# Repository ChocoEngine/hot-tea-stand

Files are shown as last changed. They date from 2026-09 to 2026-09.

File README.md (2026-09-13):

# Hot tea stand

## План оставшихся работ

1. Проверить работу датчиков и схемы: прозвонить соединения и допаять.
2. Поправить модель корпуса: исправить расположение отверстия для USB.
3. Подправить уже напечатанный корпус.
4. Отладить соединение с Zigbee-хабом SprutHub.
5. Дописать код для температурного графика.

Подставка под чашку с ESP32-C6 и NTC 3950. Структура обновлена 13 сентября 2026 года; геометрия не изменялась.

## Фотографии прототипа

Напечатанный корпус с декоративной накладкой:

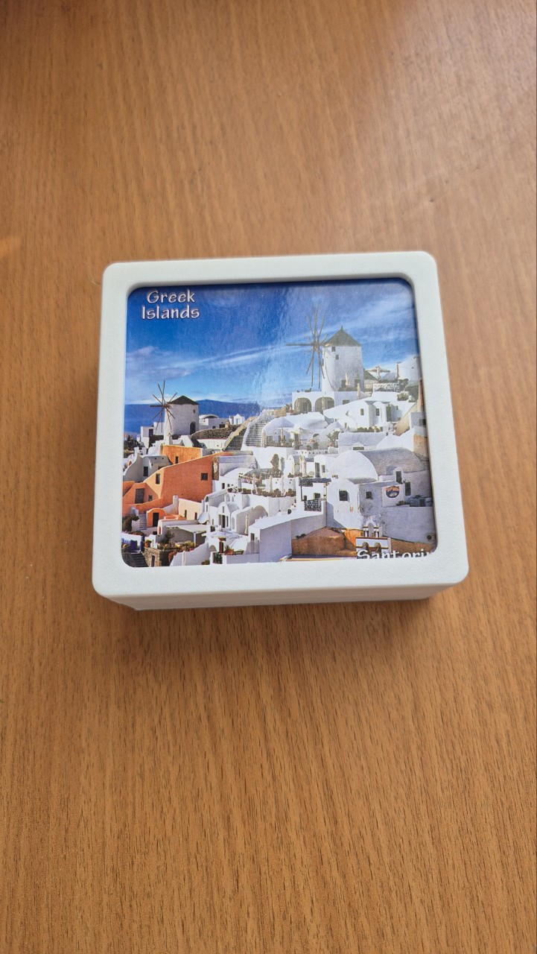
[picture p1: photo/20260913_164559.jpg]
Корпус подставки с декоративной накладкой


Внутреннее размещение ESP32-C6 на проектной плате и снятая нижняя крышка:

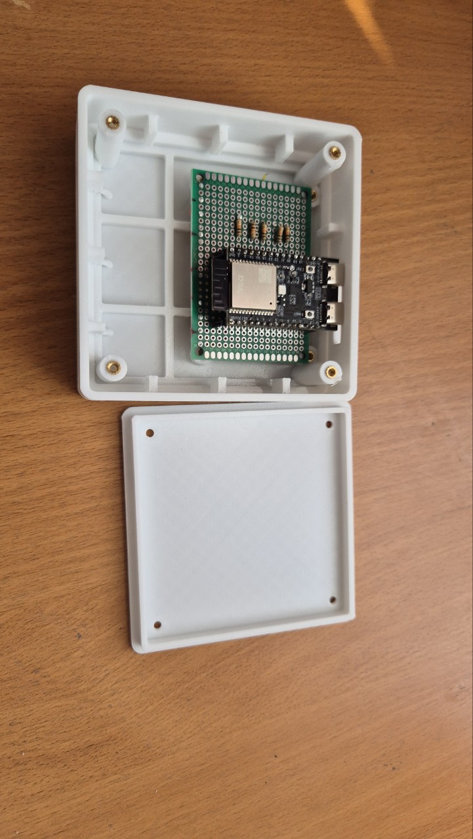
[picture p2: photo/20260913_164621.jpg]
ESP32-C6 на проектной плате внутри корпуса и нижняя крышка


## Структура

| Папка | Содержимое |
| --- | --- |
| [models/current](models/current/) | Последние модели 102 мм: исходная сборка `esp32_inverted_box_102mm_snap_lid.3dm` и результат вычитаний `esp32_inverted_box_102mm_final.3dm` |
| [models/archive](models/archive/) | Предыдущие версии 100 мм |
| [models/sketches](models/sketches/) | Рабочие эскизы `maket.3dm` |
| [models/templates](models/templates/) | Шаблон подрезки накладки 95 × 95 мм, R5 |
| [models/examples](models/examples/) | Пример прижима NTC к шайбе |
| [exports](exports/) | Сохранённые STL и 3MF; резервный STL — в `exports/archive/` |
| [scripts](scripts/) | Генерация моделей, вычитания и проверки |
| [code](code/) | Код для ESP32 и инструкция запуска |
| [docs](docs/) | Исторические заметки по корпусу и прижиму |
| [schematics](schematics/) | Схемы монтажа и макетной платы |
| [references](references/) | Фотографии и скриншоты |
| [photo](photo/) | Фотографии напечатанного прототипа и внутреннего монтажа |
| [archive/generated-cache](archive/generated-cache/) | Старый Python-кеш; для запуска не нужен |

## Актуальность файлов

`current` означает последние сохранённые файлы, а не новую проверку пригодности к печати. Соответствие `temp_box.stl` и `temp_box.3mf` последней модели не подтверждено. Ручная подрезка USB на напечатанном корпусе не означает, что CAD-файл исправлен.

Фактическая накладка оказалась размером 98 мм; отдельно сохранён шаблон подрезки до 95 мм, R5.

## Запуск скриптов

Из корня проекта:

```sh
python3 scripts/create_esp32_inverted_box_3dm.py
python3 scripts/finalize_esp32_box.py
python3 scripts/validate_esp32_box_3dm.py
python3 scripts/validate_esp32_box_final.py
```

Первые две команды перезаписывают исходную и финальную модели в `models/current/`. Перед запуском сохраняйте отдельную копию ручных изменений в Rhino: генераторы могут их не воспроизводить.

Отдельные генераторы:

```sh
python3 scripts/create_overlay_cut_template.py
python3 scripts/create_ntc_clamp_3dm.py
```

Результаты записываются в `models/templates/` и `models/examples/`. Пути вычисляются относительно скриптов и не зависят от текущей папки терминала.

Зависимости: `rhino3dm`, для операций с сетками также `numpy`, `trimesh`, `manifold3d`. Сохранены прежние дополнительные пути библиотек `/tmp/codex_rhino3dm` и `/tmp/codex_meshlibs`: это временные окружения, наличие библиотек там не гарантировано. При уборке проверен синтаксис скриптов; генерация и геометрические проверки не запускались.

## Документация и схемы

Скетч проверки пяти NTC на GPIO2–6: [code/ntc_test/ntc_test.ino](code/ntc_test/ntc_test.ino).
Подключение и запуск описаны в [code/README.md](code/README.md).

- [Заметки по корпусу](docs/README_esp32_box_ru.md) и [прижиму](docs/README_ntc_clamp_ru.md) сохранены как исторические документы: пути и размеры в них могут относиться к предыдущим итерациям.
- `schematics/esp32-perfboard-placement.html` — ранняя схема проектной платы.
- `schematics/esp32-final-perfboard-layout.html` — более поздний вариант размещения.
- `schematics/two-ntc-breadboard.html` — макет с двумя датчиками.

В схемах есть разные варианты делителя: резистор к 3V3 / NTC к GND и наоборот. Формула температуры должна соответствовать выбранному подключению. HTML сохранены как исходные фрагменты визуализаций.

Фотографии в `references/` собраны из обсуждения; их оригиналы по прежним адресам оставлены для сохранения ссылок в чате.

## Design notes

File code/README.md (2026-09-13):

# Код проверки NTC

`ntc_test/ntc_test.ino` — минимальный скетч Arduino для ESP32-C6:
пять NTC на GPIO2, GPIO3, GPIO4, GPIO5 и GPIO6, усреднение 16 измерений,
вывод напряжений в милливольтах примерно раз в секунду.
Сторонние библиотеки датчиков не нужны; используется Arduino core для ESP32.

Каждый датчик подключён отдельным делителем:

```text
3.3V ── NTC ──┬── постоянный резистор ── GND
              └── GPIO (2–6)
```

При нагревании NTC напряжение увеличивается.

Открой `ntc_test/ntc_test.ino` в Arduino IDE, выбери свою плату ESP32-C6
и порт, загрузи скетч. Скорость Serial Monitor — 115200 бод.

Температура пока не рассчитывается: нужны сопротивления постоянных
резисторов, номиналы NTC при 25 °C и коэффициенты B.

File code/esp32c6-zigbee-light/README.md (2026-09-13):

# ESP32-C6 N8: диагностическая Zigbee-лампа для SprutHub

Проект для ESP-IDF **5.3.2**, ESP Zigbee SDK **1.6.x** и ESP32-C6 с Flash 8 МБ.
Используется поддерживаемая LTS-ветка SDK 1.x для сравнения с Arduino; SDK 2.x имеет другой API и сюда не подставляется.
Зависимости загружает IDF Component Manager. После первой успешной сборки сохраните dependencies.lock для воспроизводимости.

## Поведение

- Zigbee End Device, endpoint 10, HA On/Off Light (0x0100).
- Производитель Espressif, модель ZBLightBulb; строки сохранены как в Arduino-тесте.
- Поиск подключения на канале 25, повтор после неудачи.
- В журнале: события Zigbee, успешное подключение с PAN ID/адресом/каналом, команды On/Off.
- Лампа виртуальная: GPIO нагрузки и встроенный RGB не управляются.
- BOOT (GPIO9), удерживаемая 3 секунды во время работы, сбрасывает Zigbee-привязку и перезапускает плату.
- Привязка сохраняется при обычном перезапуске.

## Открытие в VS Code

1. Установите официальное расширение **ESP-IDF** от Espressif Systems.
2. Установите/выберите **ESP-IDF 5.3.2** средствами расширения.
3. Откройте эту папку (с корневым CMakeLists.txt).
4. Запустите команду **ESP-IDF: Open ESP-IDF Terminal**.
5. Подключите левый USB-C **CH343**, выберите его последовательный порт.

## Сборка и первая прошивка

В терминале ESP-IDF, из папки проекта:

```sh
idf.py set-target esp32c6
idf.py build
idf.py -p /dev/cu.usbmodem5B3E0587871 erase-flash
idf.py -p /dev/cu.usbmodem5B3E0587871 flash monitor
```

Порт приведён из прежнего лога, он может измениться. Узнать доступные порты на macOS:

```sh
ls /dev/cu.*
```

**erase-flash нужен только при первом переходе с Arduino на эту разметку. Он удаляет всю прошивку и сохранённые данные платы, включая Zigbee-привязку.** Последующие обновления: `idf.py -p ПОРТ flash monitor` без стирания.
Закройте Serial Monitor Arduino IDE перед прошивкой. Выход из IDF Monitor: Ctrl+].

Если автоматический вход в загрузчик не работает: зажмите BOOT, нажмите и отпустите RST, отпустите BOOT и повторите flash. После прошивки нажмите RST при необходимости.

## Сопряжение

1. В SprutHub включите поиск на ZigBee_1.
2. На работающей плате удерживайте BOOT 3 секунды (не при подаче питания).
3. Дождитесь `Joined network successfully`.
4. Если вновь `Network steering was not successful`, сохраните полный вывод от `TEST-IDF-1` за 60 секунд и журнал хаба за то же время.

ESP_FAIL остаётся общим кодом: проект выводит доступные события SDK, но не является радиосниффером и не гарантирует раскрытие причины отказа. Для представления подключившейся лампы в интерфейсе SprutHub может понадобиться шаблон.

Канал меняется в main/esp_zb_light.h, ESP_ZB_PRIMARY_CHANNEL_MASK. Разметка включает zb_storage и zb_fct. Занята только часть 8 МБ; OTA в этом тесте нет.

## Проверка и источники

Структура проекта, API по заголовкам SDK и отсутствие пересечений разделов проверены. **Сборка и запуск на плате не проверены: ESP-IDF в среде подготовки не установлен.**

Основано на примере Espressif HA_on_off_light (CC0-1.0):
https://github.com/espressif/esp-zigbee-sdk/tree/release/v1.0/examples/esp_zigbee_HA_sample/HA_on_off_light

Совместимость ESP-IDF 5.3.2 рекомендована в README выбранной ветки:
https://github.com/espressif/esp-zigbee-sdk/tree/release/v1.0

Библиотеки esp-zigbee-lib и esp-zboss-lib имеют собственные лицензии; см. загружаемые компоненты.

## Если конфигуратор выбрал ESP-IDF 6.1 или target esp32

Этот проект использует API Zigbee SDK 1.x и требует ESP-IDF 5.3.x (от 5.3.2). Удалять ограничение в idf_component.yml нельзя: это не перенос на SDK 2.x.

В палитре VS Code (Cmd+Shift+P):
1. ESP-IDF: Open ESP-IDF Installation Manager — установите ESP-IDF 5.3.2 для esp32c6 рядом с 6.1.
2. ESP-IDF: Select Current ESP-IDF Version — выберите установленную 5.3.2.
3. ESP-IDF: Set Espressif Device Target — esp32c6.
4. Откройте новый ESP-IDF Terminal и выполните `idf.py --version`, затем `idf.py set-target esp32c6` и `idf.py build`.

Если старый каталог build мешает set-target, переименуйте его в build-old, сохранив для диагностики. Корневой CMakeLists.txt явно задаёт esp32c6; PROJECT_VER задан независимо от наличия коммитов Git.

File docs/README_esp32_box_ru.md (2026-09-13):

# Корпус ESP32-C6 102 × 102 мм с верхней рамкой

Актуальная модель — `esp32_inverted_box_102mm_snap_lid.3dm`. Файл создаётся
скриптом `create_esp32_inverted_box_3dm.py`. Предыдущие варианты не
перезаписываются.

## Основные размеры

- корпус: 102 × 102 × 32 мм, наружные углы R5;
- толщина основных стенок и крыши: 3 мм;
- верхнее сужение: 12 мм общей высоты;
- у основания сужения — горизонтальная опорная полка шириной 1 мм;
- после неё — скос 2 × 2 мм под 45° от 100 × 100 до 96 × 96 мм;
- следующие 10 мм — прямой участок 96 × 96 мм;
- верхняя крышка-рамка: снаружи 102 × 102 мм, R5;
- на нижнем крае крышки предусмотрен внутренний ответный скос 45° высотой 2 мм;
- накладка: 95 × 95 × 4 мм;
- карман крышки под накладку: 95,4 × 95,4 × 4,1 мм;
- квадратное окно крышки: 87 × 87 мм, углы R5;
- нахлёст рамки на накладку: 4 мм с каждой стороны;
- толщина верхней рамки: 3 мм;
- внешний верхний край крышки имеет фаску 1 × 1 мм под 45°.

Наружный контур крышки по всей высоте остаётся 102 × 102 мм. Внутренняя
полость у нижнего края начинается размером 100,4 × 100,4 мм и за 2 мм по
скосу 45° сужается до 96,4 × 96,4 мм. После этого она охватывает прямой участок
корпуса 96 × 96 мм с зазором 0,2 мм на сторону.

Крышка опускается до Z = 20 мм и нижней гранью упирается в горизонтальную
полку корпуса. Её внутренний скос повторяет наружный скос корпуса с зазором
0,2 мм на сторону. Стенка крышки у открытого края имеет печатаемую толщину
0,8 мм, а внешний контур 102 × 102 мм совпадает с основным корпусом.

## Защёлки

На каждой стороне прямого сужения находится одна впадина:

- длина 18 мм;
- высота 5 мм;
- глубина 0,8 мм;
- скосы высотой 1 мм сверху и снизу;
- положение по высоте корпуса: Z = 24…29 мм.

На крышке предусмотрены ответные выступы длиной 16 мм, высотой 5 мм и вылетом
0,65 мм. У каждого выступа также есть верхний и нижний скос по 1 мм. Размеры
рассчитаны как стартовые для PETG; перед полной печатью всё ещё желательно
проверить одну отдельную защёлку.

## Электроника и NTC

Внутренняя поверхность крыши находится на Z = 29 мм. Проектная плата
70 × 50 × 1 мм расположена в диапазонах X = 16…86, Y = 7…57 и
Z = 22…23 мм. Между ней и крышей оставлено 6 мм.

Центры монтажных отверстий Ø3 мм находятся в 2,5 мм от краёв платы:

- (18,5; 9,5);
- (83,5; 9,5);
- (18,5; 54,5);
- (83,5; 54,5).

Четыре верхние стойки переделаны под вплавляемые втулки M3 D4,5 × L4:

- наружный диаметр стойки: 9 мм;
- посадочное отверстие: Ø4,1 мм;
- глубина отверстия: 4,5 мм;
- входной скос: Ø5,1 → Ø4,1 мм, глубина 0,5 мм;
- остаток пластика между дном отверстия и крышей: 1,5 мм;
- втулки устанавливаются снизу до монтажа проектной платы.

Ниже платы показаны съёмные гребёнки высотой 8 мм и ESP32-C6 с расчётным
вертикальным габаритом 6 мм. Электронный объём занимает Z = 8…22 мм. ESP
повёрнута USB к передней стенке и смещена влево: X = 50…78 мм. Длина от
выступающей плоскости USB до края антенны принята равной 53 мм.

Для наглядности гребёнки показаны двумя отдельными рядами в предполагаемых
координатах X = 51,56 и 76,96 мм, Y = 12,08…47,64 мм. Это предварительная
привязка к сетке 2,54 мм, которую нужно сверить с реальными отверстиями платы.

Пять отверстий Ø4 мм под NTC 3950 расположены на линии Y = 51 мм. Их X:
27, 39, 51, 63 и 75 мм, шаг 12 мм. Общая длина линии датчиков — 48 мм.
Такое положение выводит крайние отверстия из объёма задних стоек проектной
платы.

Универсальное переднее окно двух USB-C имеет размер 30 × 6 мм:

- X = 49…79 мм;
- Z = 8,5…14,5 мм;
- отдельные рёбра и рамка усиления вокруг окна отсутствуют;
- над окном остаётся 5,5 мм цельной трёхмиллиметровой стенки до скоса.

Высота металлического корпуса USB принята равной 5 мм; окно оставляет суммарно
1 мм вертикального монтажного запаса.

Под всей проектной платой оставлен свободный объём с запасом 2 мм по контуру:
X = 14…88, Y = 5…59 и Z = 23…29 мм. Поэтому для выводов NTC и проводов
доступна полная высота 6 мм. В эту область входят только четыре крепёжные
стойки самой платы.

Рёбра крыши сохранены за задним краем платы, около боковых стенок и короткими
участками около передних углов. Передние стеновые рёбра расположены на X = 35
и X = 92 мм и не попадают под головки крепёжных винтов. На справочном слое
показаны свободные цилиндры Ø6 × 2,5 мм под головки винтов.

Локальные усиления вокруг USB удалены: при окне высотой 6 мм они не требуются
и мешали доступу к ближайшей стойке проектной платы.

Справочная накладка вынесена отдельно. На ней показаны пять тел для слепых
карманов 3 × 3 мм глубиной 3,1 мм.

## Нижнее винтовое дно

Дно имеет пластину 102 × 102 × 3 мм, R5, и внутренний центрирующий бортик
высотой 6 мм. Оно крепится четырьмя потайными машинными винтами M3 × 8 мм
DIN 7991 / ISO 10642.

Угловые стойки рассчитаны под вплавляемые гайки M3 D4,5 × L4:

- центры: (11; 11), (91; 11), (11; 91), (91; 91);
- наружный диаметр стойки: 9 мм;
- посадочное отверстие: Ø4,1 мм;
- глубина: 5 мм;
- входной скос: Ø5,1 → Ø4,1 мм, глубина 0,5 мм.

В дне предусмотрены отверстия Ø3,5 мм и потаи Ø7 → Ø3,5 мм глубиной 1,75 мм.

## Размещение деталей и слои

Корпус и обе крышки показаны в собранном положении и имеют общий диапазон
X = 0…102 мм:

- нижнее винтовое дно: пластина Z = −3…0 мм, вставной бортик до Z = 6 мм;
- корпус: Z = 0…32 мм;
- верхняя крышка-рамка: Z = 20…39,1 мм;
- справочная накладка остаётся отдельно: X = 122…217 мм.

Корпус, верхняя крышка и нижнее дно находятся на отдельных слоях, поэтому их
можно независимо скрывать и показывать в Rhino.

Слои:

- `01 Корпус — суженный верх 12 мм, скос 45°`;
- `02 Верхняя крышка-рамка — защёлки`;
- `03 Нижнее дно — винты M3`;
- `04 Отверстия и впадины для вычитания`;
- `05 Электроника — справочно`;
- `06 Накладка 95x95x4 — справочно`.

Красные объекты слоя 04 остаются отдельными телами для последующего
`MeshBooleanDifference`. Геометрическая проверка нового варианта намеренно не
выполнялась: сначала согласуются размеры и расположение элементов.

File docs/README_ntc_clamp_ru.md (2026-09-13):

# Прижим эпоксидного NTC к шайбе

Файл `ntc_washer_clamp_example.3dm` показывает один печатный прижим в сборе.
Он рассчитан на примерную эпоксидную каплю Ø4 × 3,5 мм и широкую шайбу M4
Ø12 × 1 мм с отверстием Ø4,3 мм.

Прижим состоит из двух крепёжных площадок, гибкой перемычки толщиной 1 мм и
центральной нажимной площадки Ø5 мм. Два винта M2 притягивают его к стойкам Ø5
мм, объединённым с внутренней поверхностью верхней панели. В стойках показаны
пилотные отверстия Ø1,6 мм для прямого вкручивания M2 в пластик.

## Сборка

1. Обезжирить нижнюю поверхность шайбы.
2. Нанести на NTC минимальный слой ARCTIC MX-4.
3. Поместить каплю непосредственно под плоскую часть шайбы.
4. Установить прижим нажимной площадкой к нижней стороне капли.
5. Равномерно затянуть два M2 без заметного изгиба шайбы.
6. Зафиксировать выводы нейтральным силиконом вне теплового контакта.

Красные цилиндры слоя `04` нужно вычесть через `MeshBooleanDifference`.
Зелёные элементы слоя `01` после вычитания объединяются командой
`MeshBooleanUnion` и печатаются одной маленькой деталью. Для пяти датчиков
прижим копируется пять раз.

Перед переносом в корпус размеры следует исправить под фактическую каплю NTC.
Для гибкой перемычки предпочтителен PETG; PLA может растрескаться при затяжке.

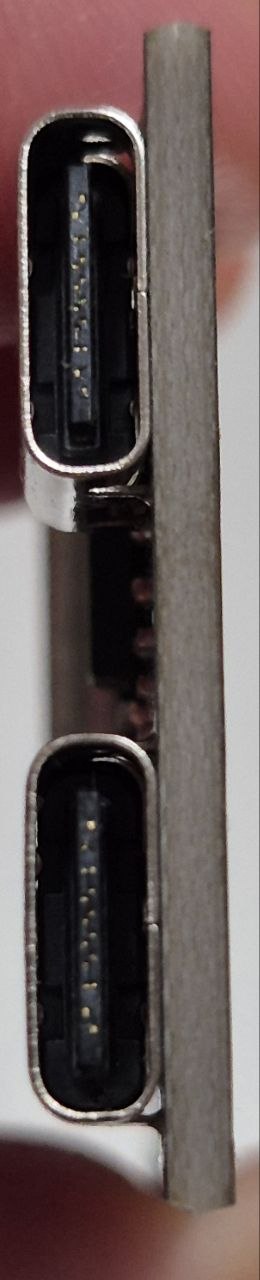
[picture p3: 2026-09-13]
references/photo_2026-09-05 03.30.40.jpeg

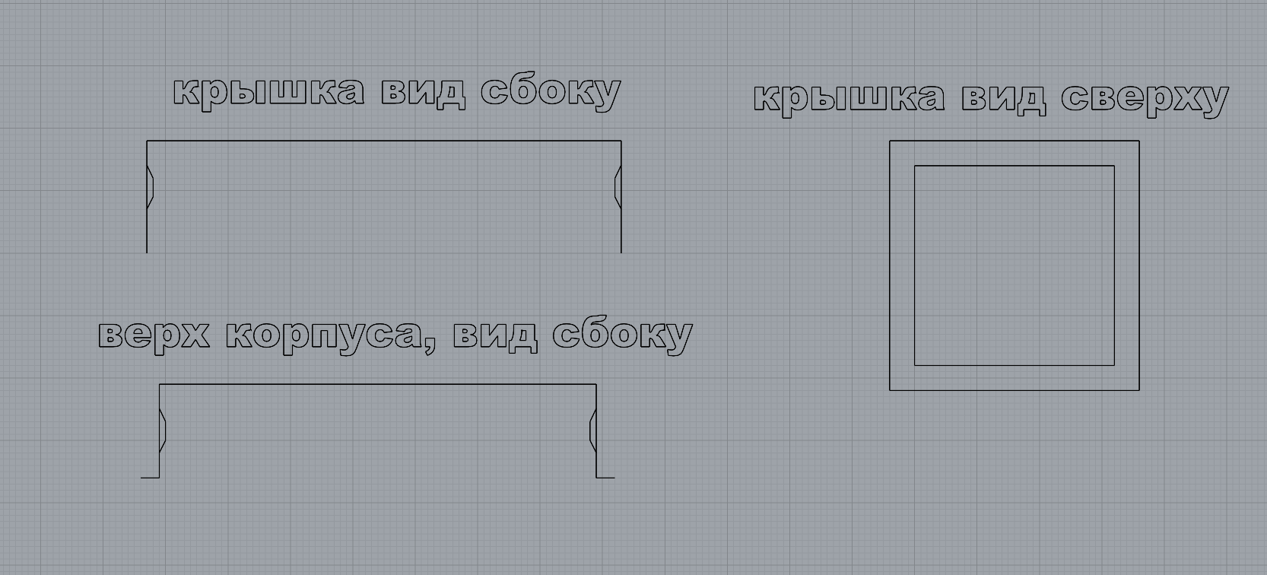
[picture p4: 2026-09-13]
references/Screenshot 2026-09-05 at 01.20.53.png

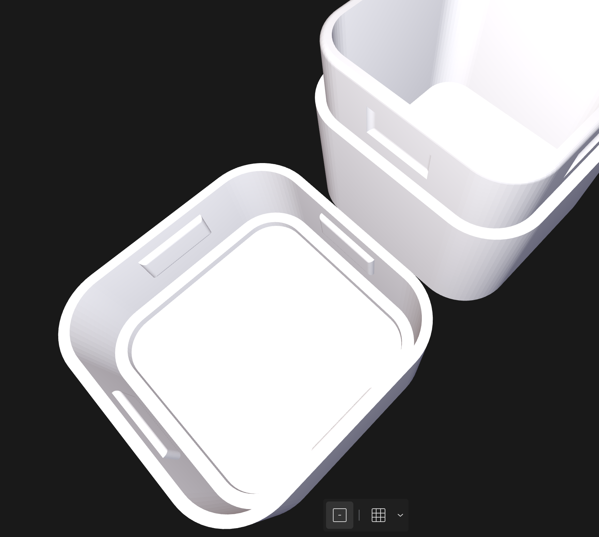
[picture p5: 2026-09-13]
references/Screenshot 2026-09-05 at 01.13.01.png

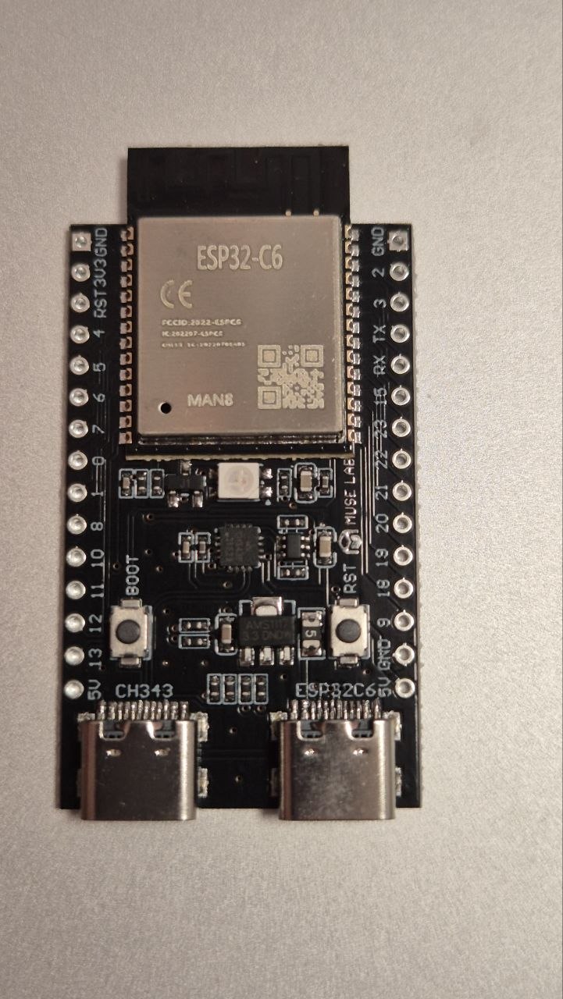
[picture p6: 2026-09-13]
references/photo_2026-09-05 02.41.20.jpeg

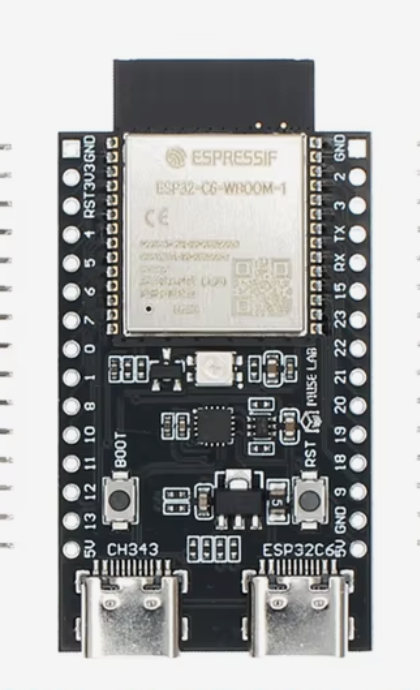
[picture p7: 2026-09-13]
references/Screenshot 2026-09-01 at 02.46.33.png

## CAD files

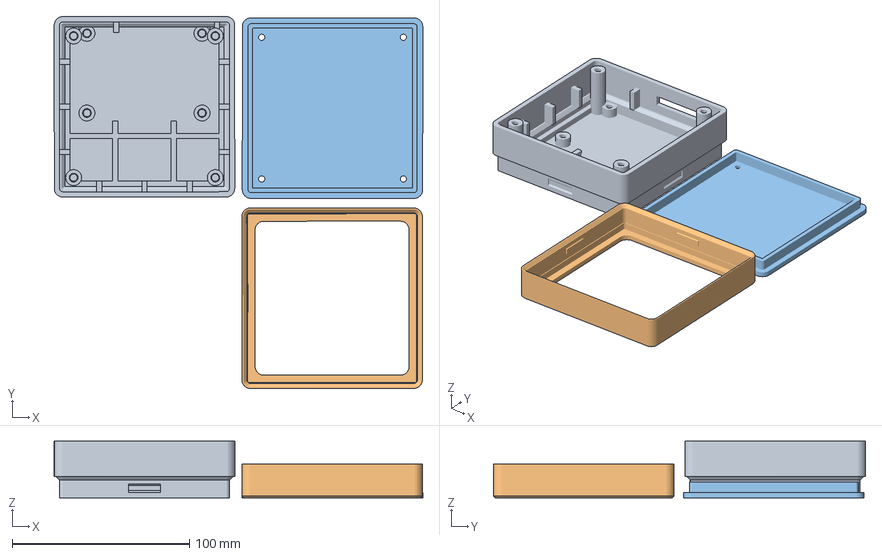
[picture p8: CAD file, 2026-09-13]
exports/temp_box.3mf
208.2 x 210.1 x 32.0 mm
temp_box.stl_1
temp_box.stl_2
temp_box.stl_3

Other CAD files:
exports/temp_box.stl
models/archive/esp32_inverted_box_100mm.3dm
models/archive/esp32_inverted_box_100mm_snap_lid.3dm
models/current/esp32_inverted_box_102mm_final.3dm
models/current/esp32_inverted_box_102mm_snap_lid.3dm
models/examples/ntc_washer_clamp_example.3dm
models/sketches/maket.3dm
models/templates/overlay_template_95x95_R5.3dm

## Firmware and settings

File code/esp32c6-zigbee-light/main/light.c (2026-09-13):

/*
 * SPDX-FileCopyrightText: 2021-2022 Espressif Systems (Shanghai) CO LTD
 *
 * SPDX-License-Identifier: CC0-1.0
 *
 * Zigbee HA_on_off_light Example
 *
 * This example code is in the Public Domain (or CC0 licensed, at your option.)
 *
 * Unless required by applicable law or agreed to in writing, this
 * software is distributed on an "AS IS" BASIS, WITHOUT WARRANTIES OR
 * CONDITIONS OF ANY KIND, either express or implied.
 */
#include "esp_zb_light.h"
#include "esp_check.h"
#include "driver/gpio.h"
#include "esp_log.h"
#include "nvs_flash.h"
#include "freertos/FreeRTOS.h"
#include "freertos/task.h"
#include "ha/esp_zigbee_ha_standard.h"

#if !defined ZB_ED_ROLE
#error Define ZB_ED_ROLE in idf.py menuconfig to compile light (End Device) source code.
#endif

static const char *TAG = "ESP_ZB_ON_OFF_LIGHT";
/********************* Define functions **************************/
// BOOT on ESP32-C6 is GPIO9. Poll from the Zigbee scheduler context.
static void poll_boot(uint8_t unused)
{
    static unsigned held = 0;
    held = gpio_get_level(GPIO_NUM_9) == 0 ? held + 1 : 0;
    if (held >= 30) {
        ESP_LOGW(TAG, "BOOT held 3 seconds: erase Zigbee pairing and reboot");
        esp_zb_factory_reset();
        return;
    }
    esp_zb_scheduler_alarm(poll_boot, 0, 100);
}

static void bdb_start_top_level_commissioning_cb(uint8_t mode_mask)
{
    ESP_RETURN_ON_FALSE(esp_zb_bdb_start_top_level_commissioning(mode_mask) == ESP_OK, , TAG, "Failed to start Zigbee commissioning");
}

void esp_zb_app_signal_handler(esp_zb_app_signal_t *signal_struct)
{
    uint32_t *p_sg_p       = signal_struct->p_app_signal;
    esp_err_t err_status = signal_struct->esp_err_status;
    esp_zb_app_signal_type_t sig_type = *p_sg_p;
    switch (sig_type) {
    case ESP_ZB_ZDO_SIGNAL_SKIP_STARTUP:
        ESP_LOGI(TAG, "Initialize Zigbee stack");
        esp_zb_bdb_start_top_level_commissioning(ESP_ZB_BDB_MODE_INITIALIZATION);
        break;
    case ESP_ZB_BDB_SIGNAL_DEVICE_FIRST_START:
    case ESP_ZB_BDB_SIGNAL_DEVICE_REBOOT:
        if (err_status == ESP_OK) {

            ESP_LOGI(TAG, "Device started up in%s factory-reset mode", esp_zb_bdb_is_factory_new() ? "" : " non");
            if (esp_zb_bdb_is_factory_new()) {
                ESP_LOGI(TAG, "Start network steering");
                esp_zb_bdb_start_top_level_commissioning(ESP_ZB_BDB_MODE_NETWORK_STEERING);
            } else {
                ESP_LOGI(TAG, "Device rebooted");
            }
        } else {
            ESP_LOGW(TAG, "%s failed with status: %s, retrying", esp_zb_zdo_signal_to_string(sig_type),
                     esp_err_to_name(err_status));
            esp_zb_scheduler_alarm((esp_zb_callback_t)bdb_start_top_level_commissioning_cb,
                                   ESP_ZB_BDB_MODE_INITIALIZATION, 1000);
        }
        break;
    case ESP_ZB_BDB_SIGNAL_STEERING:
        if (err_status == ESP_OK) {
            esp_zb_ieee_addr_t extended_pan_id;
            esp_zb_get_extended_pan_id(extended_pan_id);
            ESP_LOGI(TAG, "Joined network successfully (Extended PAN ID: %02x:%02x:%02x:%02x:%02x:%02x:%02x:%02x, PAN ID: 0x%04hx, Channel:%d, Short Address: 0x%04hx)",
                     extended_pan_id[7], extended_pan_id[6], extended_pan_id[5], extended_pan_id[4],
                     extended_pan_id[3], extended_pan_id[2], extended_pan_id[1], extended_pan_id[0],
                     esp_zb_get_pan_id(), esp_zb_get_current_channel(), esp_zb_get_short_address());
        } else {
            ESP_LOGI(TAG, "Network steering was not successful (status: %s)", esp_err_to_name(err_status));
            esp_zb_scheduler_alarm((esp_zb_callback_t)bdb_start_top_level_commissioning_cb, ESP_ZB_BDB_MODE_NETWORK_STEERING, 1000);
        }
        break;
    default:
        ESP_LOGI(TAG, "ZDO signal: %s (0x%x), status: %s", esp_zb_zdo_signal_to_string(sig_type), sig_type,
                 esp_err_to_name(err_status));
        break;
    }
}

static esp_err_t zb_attribute_handler(const esp_zb_zcl_set_attr_value_message_t *message)
{
    esp_err_t ret = ESP_OK;
    bool light_state = 0;

    ESP_RETURN_ON_FALSE(message, ESP_FAIL, TAG, "Empty message");
    ESP_RETURN_ON_FALSE(message->info.status == ESP_ZB_ZCL_STATUS_SUCCESS, ESP_ERR_INVALID_ARG, TAG, "Received message: error status(%d)",
                        message->info.status);
    ESP_LOGI(TAG, "Received message: endpoint(%d), cluster(0x%x), attribute(0x%x), data size(%d)", message->info.dst_endpoint, message->info.cluster,
             message->attribute.id, message->attribute.data.size);
    if (message->info.dst_endpoint == HA_ESP_LIGHT_ENDPOINT) {
        if (message->info.cluster == ESP_ZB_ZCL_CLUSTER_ID_ON_OFF) {
            if (message->attribute.id == ESP_ZB_ZCL_ATTR_ON_OFF_ON_OFF_ID && message->attribute.data.type == ESP_ZB_ZCL_ATTR_TYPE_BOOL) {
                light_state = message->attribute.data.value ? *(bool *)message->attribute.data.value : light_state;
                ESP_LOGI(TAG, "Light sets to %s", light_state ? "On" : "Off");
                // Diagnostic lamp: command is logged; no external load is connected.
            }
        }
    }
    return ret;
}

static esp_err_t zb_action_handler(esp_zb_core_action_callback_id_t callback_id, const void *message)
{
    esp_err_t ret = ESP_OK;
    switch (callback_id) {
    case ESP_ZB_CORE_SET_ATTR_VALUE_CB_ID:
        ret = zb_attribute_handler((esp_zb_zcl_set_attr_value_message_t *)message);
        break;
    default:
        ESP_LOGW(TAG, "Receive Zigbee action(0x%x) callback", callback_id);
        break;
    }
    return ret;
}

static void esp_zb_task(void *pvParameters)
{
    /* initialize Zigbee stack */
    esp_zb_cfg_t zb_nwk_cfg = ESP_ZB_ZED_CONFIG();
    esp_zb_init(&zb_nwk_cfg);
    esp_zb_on_off_light_cfg_t light_cfg = ESP_ZB_DEFAULT_ON_OFF_LIGHT_CONFIG();
    esp_zb_ep_list_t *esp_zb_on_off_light_ep = esp_zb_on_off_light_ep_create(HA_ESP_LIGHT_ENDPOINT, &light_cfg);
    static char manufacturer[] = "\x09" "Espressif";
    static char model[] = "\x0b" "ZBLightBulb";
    esp_zb_cluster_list_t *clusters = esp_zb_ep_list_get_ep(esp_zb_on_off_light_ep, HA_ESP_LIGHT_ENDPOINT);
    esp_zb_attribute_list_t *basic = esp_zb_cluster_list_get_cluster(clusters, ESP_ZB_ZCL_CLUSTER_ID_BASIC, ESP_ZB_ZCL_CLUSTER_SERVER_ROLE);
    ESP_ERROR_CHECK(esp_zb_basic_cluster_add_attr(basic, ESP_ZB_ZCL_ATTR_BASIC_MANUFACTURER_NAME_ID, manufacturer));
    ESP_ERROR_CHECK(esp_zb_basic_cluster_add_attr(basic, ESP_ZB_ZCL_ATTR_BASIC_MODEL_IDENTIFIER_ID, model));
    ESP_ERROR_CHECK(esp_zb_device_register(esp_zb_on_off_light_ep));
    esp_zb_core_action_handler_register(zb_action_handler);
    ESP_ERROR_CHECK(esp_zb_set_primary_network_channel_set(ESP_ZB_PRIMARY_CHANNEL_MASK));
    esp_zb_bdb_set_scan_duration(4);
    ESP_LOGI(TAG, "TEST-IDF-1: endpoint 10, channel 25, hold BOOT 3s to reset pairing");
    ESP_ERROR_CHECK(esp_zb_start(false));
    esp_zb_scheduler_alarm(poll_boot, 0, 100);
    esp_zb_stack_main_loop();
}

void app_main(void)
{
    esp_zb_platform_config_t config = {
        .radio_config = ESP_ZB_DEFAULT_RADIO_CONFIG(),
        .host_config = ESP_ZB_DEFAULT_HOST_CONFIG(),
    };
    gpio_config_t boot = {
        .pin_bit_mask = 1ULL << GPIO_NUM_9,
        .mode = GPIO_MODE_INPUT,
        .pull_up_en = GPIO_PULLUP_ENABLE,
    };
    ESP_ERROR_CHECK(gpio_config(&boot));
    esp_err_t err = nvs_flash_init();
    if (err == ESP_ERR_NVS_NO_FREE_PAGES || err == ESP_ERR_NVS_NEW_VERSION_FOUND) {
        ESP_ERROR_CHECK(nvs_flash_erase());
        err = nvs_flash_init();
    }
    ESP_ERROR_CHECK(err);
    ESP_ERROR_CHECK(esp_zb_platform_config(&config));
    ESP_ERROR_CHECK(xTaskCreate(esp_zb_task, "Zigbee_main", 8192, NULL, 5, NULL) == pdPASS ? ESP_OK : ESP_ERR_NO_MEM);
}

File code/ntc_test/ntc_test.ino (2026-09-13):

#include <Arduino.h>

// Each divider: 3.3V -> NTC -> GPIO junction -> fixed resistor -> GND.
// Heating the NTC increases the measured voltage.
constexpr uint8_t NTC_PINS[] = {2, 3, 4, 5, 6};
constexpr size_t NTC_COUNT = sizeof(NTC_PINS) / sizeof(NTC_PINS[0]);
constexpr int SAMPLES = 16;

void setup() {
  Serial.begin(115200);
  analogReadResolution(12);

  for (size_t i = 0; i < NTC_COUNT; ++i) {
    pinMode(NTC_PINS[i], INPUT);
    analogSetPinAttenuation(NTC_PINS[i], ADC_11db);
  }

  delay(500);
  Serial.println("Five NTC test: GPIO2-6");
}

void loop() {
  uint32_t sums[NTC_COUNT] = {};

  for (int sample = 0; sample < SAMPLES; ++sample) {
    for (size_t i = 0; i < NTC_COUNT; ++i) {
      sums[i] += analogReadMilliVolts(NTC_PINS[i]);
    }
    delay(2);
  }

  for (size_t i = 0; i < NTC_COUNT; ++i) {
    if (i > 0) {
      Serial.print(" | ");
    }
    Serial.printf(
      "NTC%u GPIO%u: %lu mV",
      static_cast<unsigned>(i + 1),
      static_cast<unsigned>(NTC_PINS[i]),
      static_cast<unsigned long>(sums[i] / SAMPLES)
    );
  }

  Serial.println();
  delay(1000);
}

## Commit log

2026-09-13 Initial commit: hot tea stand models, firmware and documentation
    [esp32_inverted_box_100mm.3dm, esp32_inverted_box_100mm_snap_lid.3dm, esp32_inverted_box_102mm_final.3dm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]
2026-09-13 Add prototype photos to README
